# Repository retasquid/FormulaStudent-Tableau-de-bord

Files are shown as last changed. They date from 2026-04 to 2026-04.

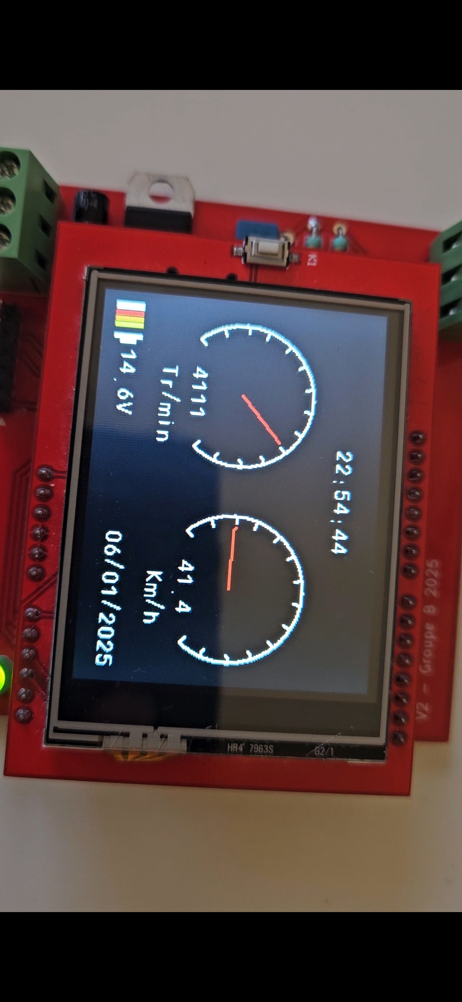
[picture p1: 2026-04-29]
photos/Page_ecran.jpg

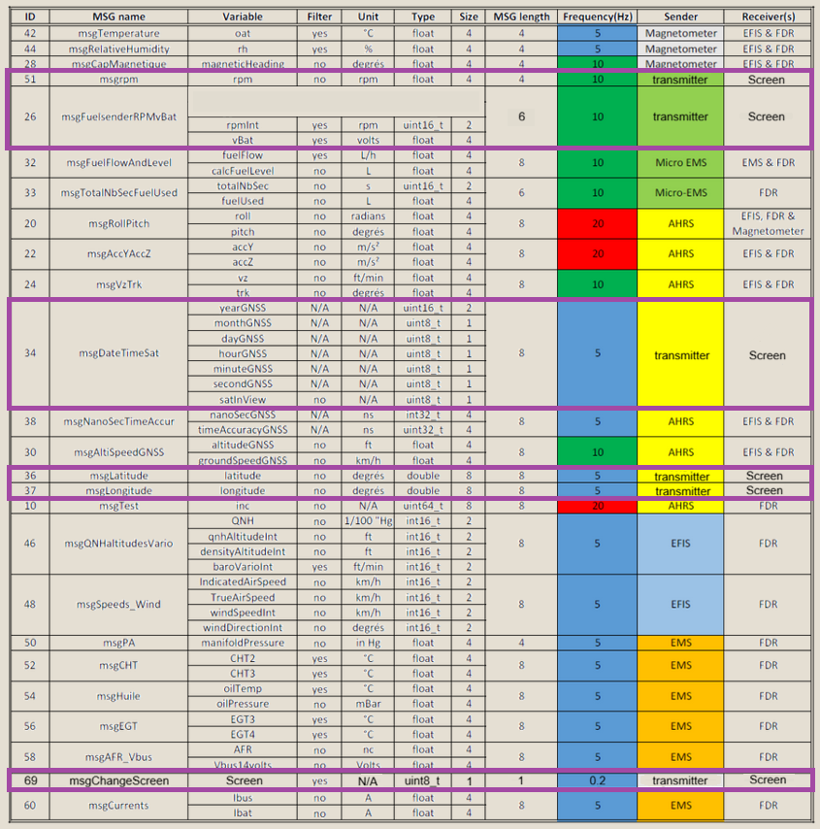
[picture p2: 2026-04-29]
photos/Correspondance_mesure_can_annote.PNG

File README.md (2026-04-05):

# 🏎️ PROJET FORMULA STUDENT - Système d'Affichage Temps Réel

Je suis fier de vous présenter notre travail réalisé dans le cadre du projet Formula Student à l'IUT Lyon 1 Villeurbanne Gratte-Ciel !

# 📍 Contexte :
Dans cette compétition automobile étudiante, plusieurs spécialités et groupes collaborent pour concevoir un véhicule de course. Matthia Pretotto et moi avons travaillé sur le système d'affichage des données du véhicule.

# ⚙️ Objectif du projet :
Développer un système capable d'acquérir, traiter et afficher en temps réel les données du tableau de bord via le bus CAN de la voiture de course.

# 📊 Fonctionnalités implémentées :
• Vitesse instantanée du véhicule
• Régime moteur (RPM)
• Heure actuelle
• Tension batterie
• Position GPS du véhicule

# 🛠️ Technologies employées :
Le projet se base sur un microcontrôleur 8 bits PIC18F27Q84 et un transceiver CAN pour interfacer le bus CAN. Le software a été réalisé en C depuis l'IDE MPLABX avec le plugin MCC pour simplifier la configuration des périphériques. Nous avons également conçu la carte électronique puis nous l'avons fait imprimer par un professionnel.

# 💡 Défis techniques relevés :
Les contraintes principales du projet étaient de réussir à rafraîchir rapidement l'écran malgré les limitations du microcontrôleur PIC et d'assurer une réception fiable des données provenant du bus CAN. Pour ce faire, nous avons développé des bibliothèques optimisées pour interagir efficacement avec le bus CAN et accélérer le calcul des jauges de l'écran, atteignant ainsi un taux de rafraîchissement d'environ 3Hz.

Merci à Mr. Ismael Bakiri et Mr. Anthony Chaussat pour leur encadrement et leur soutien tout au long de ce projet.

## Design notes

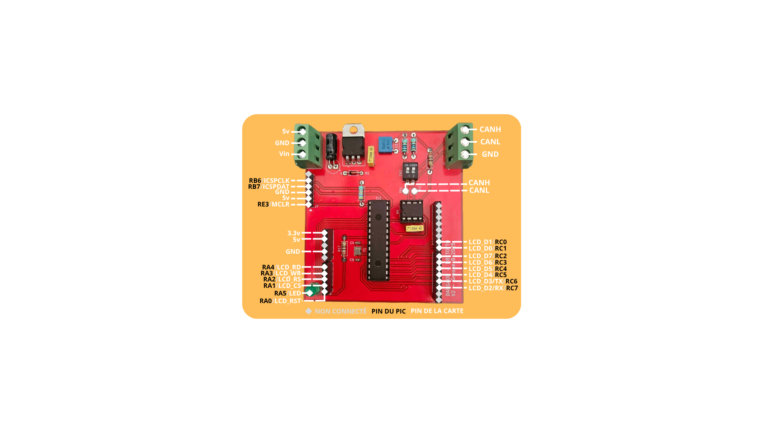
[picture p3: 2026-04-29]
photos/Carte_Formula_Student_Pinout.png

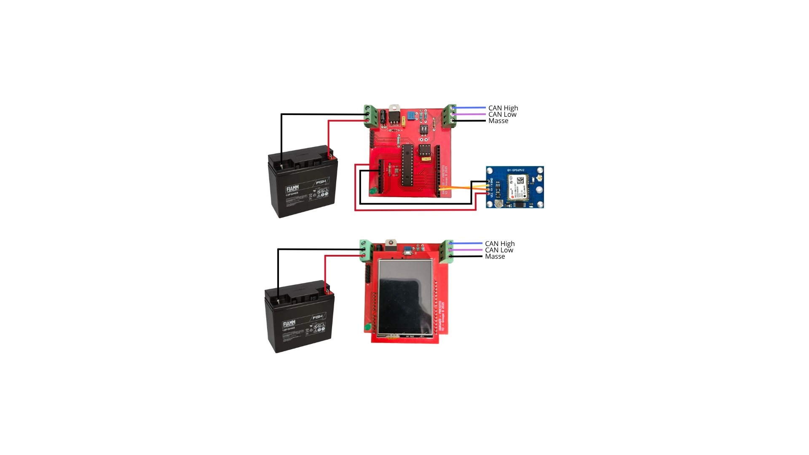
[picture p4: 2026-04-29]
photos/Cablage_cartes.png

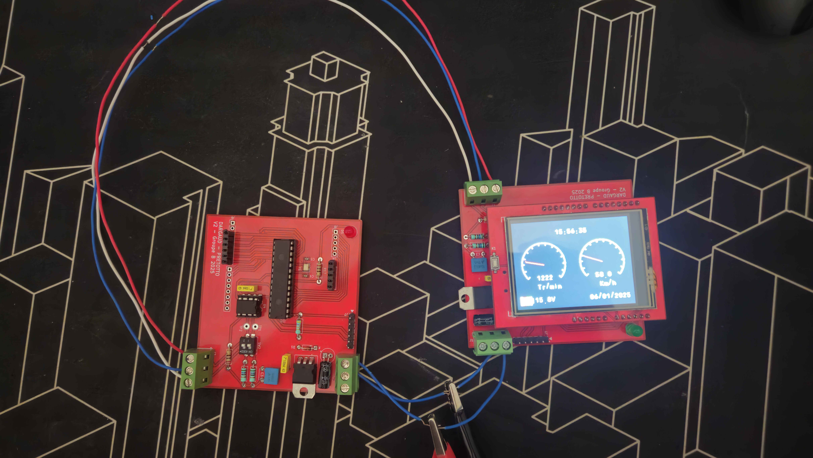
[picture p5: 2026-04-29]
photos/Cablage_reel_cartes.jpg

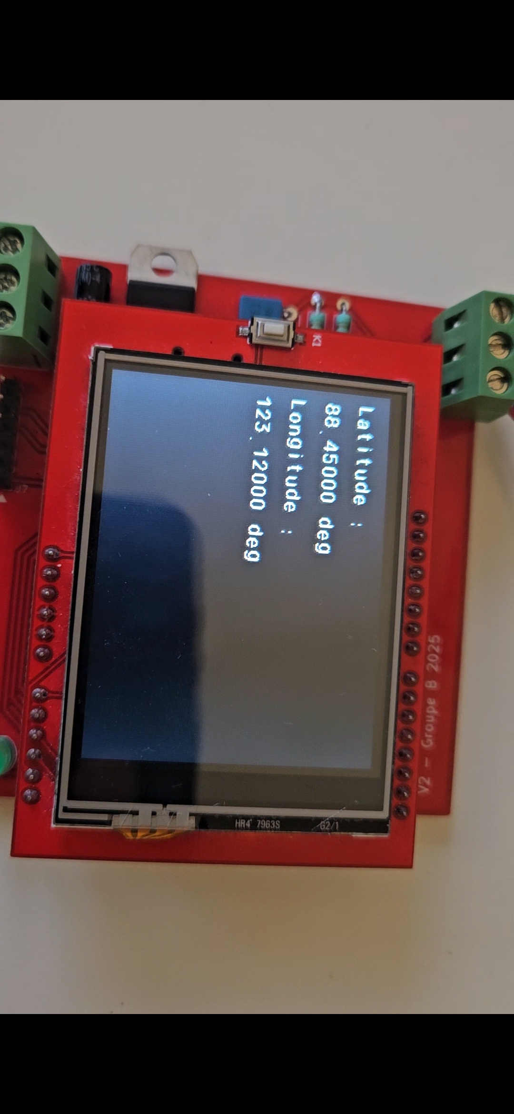
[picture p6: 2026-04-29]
photos/page_position.jpg

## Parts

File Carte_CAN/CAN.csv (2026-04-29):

Reference | Value | Footprint | Qty | Description
C1,C2 | 100 nF | IUT_CAO_empreintes:C_Disc_D4.7mm_W2.5mm_P5.00mm | 2 | Unpolarized capacitor
C3 | 10 nF | IUT_CAO_empreintes:C_Disc_D4.7mm_W2.5mm_P5.00mm | 1 | Unpolarized capacitor
C4,C5 | 20pF | Capacitor_SMD:C_0603_1608Metric | 2 | Unpolarized capacitor
C21 | 1uF | IUT_CAO_empreintes:CP_Radial_D6.3mm_P2.50mm | 1 | polarized capacitor
D1 | 1N4148 | Diode_THT:D_DO-35_SOD27_P7.62mm_Horizontal | 1 | 100V 0.15A standard switching diode, DO-35
D5 | LED | IUT_CAO_empreintes:LED_D5.0mm | 1
J1,J2 | Screw_Terminal_01x03 | G207_Laury_empreintes: Bornier_1x03_L15mm_W7.5mm_P5.00mm | 2 | Generic screw terminal, single row, 01x03
J3,J6 | Conn_01x08_Socket | Connector_PinHeader_2.54mm: PinHeader_1x08_P2.54mm_Vertical | 2 | Generic connector, single row, 01x08, script generated
J4,J8 | Conn_01x05_Socket | Connector_PinHeader_2.54mm: PinHeader_1x05_P2.54mm_Vertical | 2 | Generic connector, single row, 01x05, script generated
J7 | Conn_01x06_Pin | IUT_CAO_empreintes:PinHeader_1x06_P2.54mm_Vertical | 1
R14 | 47k | G207_Laury_empreintes: R_Axial_DIN0207_L6.3mm_D2.5mm_P10.16mm_Horizontal | 1
R17 | 270 | G207_Laury_empreintes: R_Axial_DIN0207_L6.3mm_D2.5mm_P10.16mm_Horizontal | 1
R18,R19 | 60 | G207_Laury_empreintes: R_Axial_DIN0207_L6.3mm_D2.5mm_P10.16mm_Horizontal | 2
R20 | 300 | G207_Laury_empreintes: R_Axial_DIN0207_L6.3mm_D2.5mm_P10.16mm_Horizontal | 1
SW2 | SW_DIP_x02 | IUT_CAO_empreintes: SW_DIP_SPSTx02_Slide_7.5x7.01mm_W7.62mm_P2.54mm_LowProfile | 1 | 2x DIP Switch, Single Pole Single Throw (SPST) switch, small symbol
TP1,TP2 | TestPoint | IUT_CAO_empreintes: TestPoint_Loop_D2.50mm_Drill1.0mm | 2 | test point
U1 | PIC18F27Q84 | PIC18F27Q84-E_SP:DIP787W45P254L3556H508Q28 | 1
U4 | MCP2561-E-P | Package_DIP:DIP-8_W7.62mm_LongPads | 1 | High-Speed CAN Transceiver, 1Mbps, 5V supply, -40C to +125C, DIP-8
U8 | L7805 | L7805CV:TO255P1040X460X1968-3 | 1 | Positive 1.5A 35V Linear Regulator, Fixed Output 5V, TO-220/TO-263/TO-252
Y1 | Crystal_GND23 | Crystal:Crystal_SMD_3225-4Pin_3.2x2.5mm | 1 | Four pin crystal, GND on pins 2 and 3
Screen | 2.4” TFT LCD | 4DLCD-24320240-IPS Arduino Shield Compatible | 1 | 2.4” TFT LCD Arduino Shield Compatible
GPS | Ublox NEO-6M | Connector_PinHeader_2.54mm: PinHeader_1x04_P2.54mm_Vertical | 1 | Ublox NEO-6M based GPS board

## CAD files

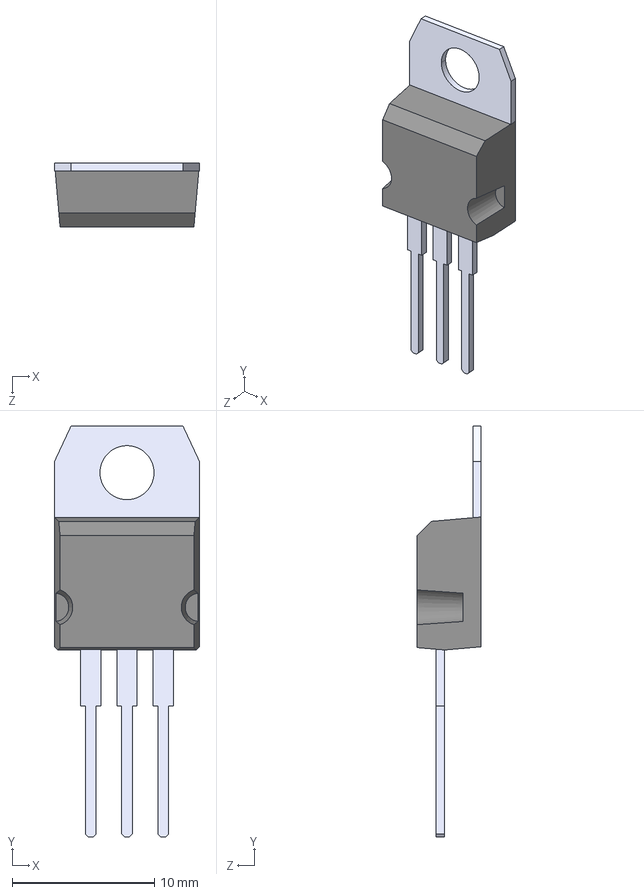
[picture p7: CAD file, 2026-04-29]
Carte_CAN/L7805CV/L7805CV.step
10.2 x 28.9 x 4.50 mm

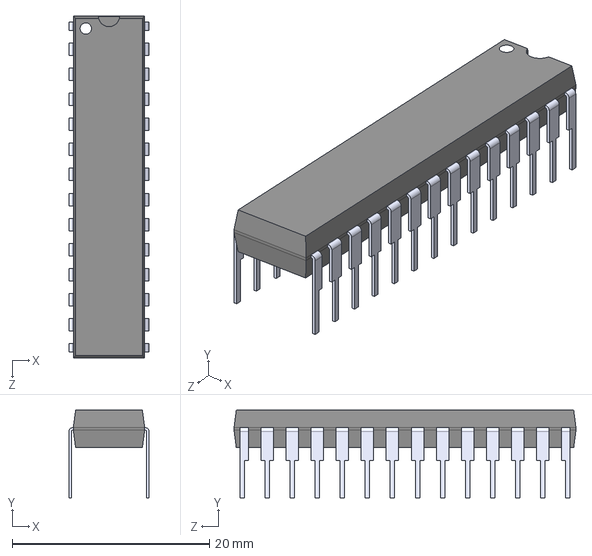
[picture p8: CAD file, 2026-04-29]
Carte_CAN/PIC18F27Q84-E_SP/PIC18F27Q84-E_SP.step
8.13 x 8.89 x 34.7 mm

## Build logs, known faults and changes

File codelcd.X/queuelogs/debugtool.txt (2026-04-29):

389 1761028267058 GEN4_TO_CONTROLLER_LOG:GEN4_PROGRAM_INT_LOG_PIC18F27Q84 Pre:endOfOperations
389 1761028267058 GEN4_TO_CONTROLLER_LOG:GEN4_PROGRAM_INT_LOG_PIC18F27Q84 Payload
389 1761028267058 GEN4_TO_CONTROLLER_LOG:GEN4_PROGRAM_INT_LOG_PIC18F27Q84 null
389 1761028267058 GEN4_TO_CONTROLLER_LOG:GEN4_PROGRAM_INT_LOG_PIC18F27Q84 Payload End
389 1761028267058 XXXX 1761028267058, Thread 389: XXXX 1761028267058, Entering Thread 389: Commands::runScriptBasic, script name = ExitTMOD, timeOut = -1 ms  
389 1761028267058 XXXX 1761028267058, Thread 389: com.Send returned false 
389 1761028267058 XXXX 1761028267058, Thread 389: transfer: exception after writeHeaderAndGetResult null 
389 1761028267058 XXXX 1761028267058, Thread 389: XXXX 1761028267058, Entering Thread 389: ToolCommUsb::recoverFromProtocolError, type = NO_SCRIPT  
389 1761028267058 XXXX 1761028267058, Thread 389: Send Abort Script Engine Command 
389 1761028267058 XXXX 1761028267058, Thread 389: XXXX 1761028267058, Entering Thread 389: ToolCommUsb::killScriptEngine  
389 1761028267059 XXXX 1761028267059, Thread 389: com.Send returned false 
389 1761028267059 XXXX 1761028267059, Thread 389: Failed sending Abort Script Engine Command. Set nuclear option = true 
389 1761028267059 XXXX 1761028267059, Thread 389: About to nuke 
389 1761028267059 XXXX 1761028267059, Thread 389: XXXX 1761028267059, Entering Thread 389: ToolCommUsb::nuclearOption  
389 1761028267060 XXXX 1761028267060, Thread 389: com.Send returned false

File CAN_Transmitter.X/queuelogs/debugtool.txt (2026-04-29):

340 1774035285568 GEN4_CONNECT_DIAGNOSTICS:MPLABCommTool is NOT null
340 1774035285568 GEN4_CONNECT_DIAGNOSTICS:AttachedToolPID = 9018, AttachedToolVID = 4d8
340 1774035285568 GEN4_CONNECT_DIAGNOSTICS:transport type = USB
340 1774035285568 GEN4_CONNECT_DIAGNOSTICS:AttachedToolPID = 9018, AttachedToolVID = 4d8
340 1774035286806 com.microchip.mplab.mdbcore.RealICETool.RIDbgToolCom
340 1774035286806 GEN4_CONNECT_DIAGNOSTICS:Before MPLABCommTool.Connect()
340 1774035286807 GEN4_CONNECT_DIAGNOSTICS:After MPLABCommTool.Connect()
340 1774035286807 GEN4_CONNECT_DIAGNOSTICS:MPLABCommTool.Connect() returned MPLABCOMM_NO_ERROR
340 1774035286807 GEN4_CONNECT_DIAGNOSTICS:Attaching to MPLABCommTool plugnplay
340 1774035286825 GEN4_CONNECT_DIAGNOSTICS:Adding new plug and play observer com.microchip.mplab.mdbcore.RI4Tool.RI4ToolBase$RI4PlugNPlayObserver@11f38d99
340 1774035286825 GEN4_CONNECT_DIAGNOSTICS:Begin PlugNPlayObservers list dump:
340 1774035286825 GEN4_CONNECT_DIAGNOSTICS:com.microchip.mplab.mdbcore.RI4Tool.RI4ToolBase$RI4PlugNPlayObserver@11f38d99
340 1774035286825 GEN4_CONNECT_DIAGNOSTICS:End PlugNPlayObservers list dump:
340 1774035286850 GEN4_CONNECT_DIAGNOSTICS:Registering for alternate PNP notifications. CommPnPCriteria.cPIDList = [9019, 901c, 2180], CommPnPCriteria.cSerialNumber = bur205171127
148 1774035287709 GEN4_CONNECT_DIAGNOSTICS:Calling Update on plug and play observer com.microchip.mplab.mdbcore.RI4Tool.RI4ToolBase$RI4PlugNPlayObserver@11f38d99
148 1774035287709 GEN4_CONNECT_DIAGNOSTICS:Entering plug and play Update(). Attached PID = 9018
148 1774035288523 com.microchip.mplab.mdbcore.RealICETool.RIDbgToolCom.HWToolConnected
148 1774035288523 GEN4_CONNECT_DIAGNOSTICS:Before MPLABCommTool.Connect()
148 1774035288523 GEN4_CONNECT_DIAGNOSTICS:After MPLABCommTool.Connect()
148 1774035288523 GEN4_CONNECT_DIAGNOSTICS:MPLABCommTool.Connect() returned MPLABCOMM_NO_ERROR
148 1774035288523 GEN4_CONNECT_DIAGNOSTICS:Before detaching from MPLABCommTool plugnplay
148 1774035288524 GEN4_CONNECT_DIAGNOSTICS:Attaching to MPLABCommTool plugnplay
148 1774035288524 GEN4_CONNECT_DIAGNOSTICS:Calling Update on plug and play observer com.microchip.mplab.mdbcore.RI4Tool.RI4ToolBase$RI4PlugNPlayObserver@11f38d99
148 1774035288524 GEN4_CONNECT_DIAGNOSTICS:Entering plug and play Update(). Attached PID = 9018
148 1774035292241 GEN4_CONNECT_DIAGNOSTICS:Calling Update on plug and play observer com.microchip.mplab.mdbcore.RI4Tool.RI4ToolBase$RI4PlugNPlayObserver@11f38d99
148 1774035292241 GEN4_CONNECT_DIAGNOSTICS:Entering plug and play Update(). Attached PID = 9018
148 1774035293047 com.microchip.mplab.mdbcore.RealICETool.RIDbgToolCom.HWToolConnected
148 1774035293047 GEN4_CONNECT_DIAGNOSTICS:Before MPLABCommTool.Connect()
148 1774035293047 GEN4_CONNECT_DIAGNOSTICS:After MPLABCommTool.Connect()
148 1774035293047 GEN4_CONNECT_DIAGNOSTICS:MPLABCommTool.Connect() returned MPLABCOMM_NO_ERROR
148 1774035293047 GEN4_CONNECT_DIAGNOSTICS:Before detaching from MPLABCommTool plugnplay
148 1774035293047 GEN4_CONNECT_DIAGNOSTICS:Attaching to MPLABCommTool plugnplay
148 1774035293047 GEN4_CONNECT_DIAGNOSTICS:Calling Update on plug and play observer com.microchip.mplab.mdbcore.RI4Tool.RI4ToolBase$RI4PlugNPlayObserver@11f38d99
148 1774035293047 GEN4_CONNECT_DIAGNOSTICS:Entering plug and play Update(). Attached PID = 9018

340 1774035297469 GEN4_TO_CONTROLLER_LOG:GEN4_INIT_INT_LOG_PIC18F27Q84 Pre:init
340 1774035297469 GEN4_TO_CONTROLLER_LOG:GEN4_INIT_INT_LOG_PIC18F27Q84 Payload
340 1774035297469 GEN4_TO_CONTROLLER_LOG:GEN4_INIT_INT_LOG_PIC18F27Q84 DeviceInfo: Values:
340 1774035297470 GEN4_TO_CONTROLLER_LOG:GEN4_INIT_INT_LOG_PIC18F27Q84 DeviceInfo: pcAddress = 000004f9, Vpp = 9,00, useRowEraseIfVoltageIsLow = true, voltageBelowWhichUseRowErase = 2,10, deviceName = PIC18F27Q84, programmerType = PIC18ENH_V2
340 1774035297470 GEN4_TO_CONTROLLER_LOG:GEN4_INIT_INT_LOG_PIC18F27Q84 DeviceInfo: MemInfo values:
340 1774035297470 GEN4_TO_CONTROLLER_LOG:GEN4_INIT_INT_LOG_PIC18F27Q84 DeviceInfo: mask = ffff, exists = true, startAddr = 00000000, endAddr = 0001ffff, rowSize = 0080, rowEraseSize = 0080, addrInc = 0002, widthProgram = 0002
340 1774035297470 GEN4_TO_CONTROLLER_LOG:GEN4_INIT_INT_LOG_PIC18F27Q84 DeviceInfo: mask = 00ff, exists = true, startAddr = 00300000, endAddr = 00300023, rowSize = 0001, rowEraseSize = 0000, addrInc = 0001, widthProgram = 0001
340 1774035297470 GEN4_TO_CONTROLLER_LOG:GEN4_INIT_INT_LOG_PIC18F27Q84 DeviceInfo: mask = 0000, exists = false, startAddr = 00000000, endAddr = 00000000, rowSize = 0000, rowEraseSize = 0080, addrInc = 0000, widthProgram = 0000
340 1774035297470 GEN4_TO_CONTROLLER_LOG:GEN4_INIT_INT_LOG_PIC18F27Q84 DeviceInfo: mask = 00ff, exists = true, startAddr = 00380000, endAddr = 003803ff, rowSize = 0001, rowEraseSize = 0000, addrInc = 0001, widthProgram = 0001
340 1774035297470 GEN4_TO_CONTROLLER_LOG:GEN4_INIT_INT_LOG_PIC18F27Q84 DeviceInfo: mask = ffff, exists = true, startAddr = 00200000, endAddr = 0020003f, rowSize = 0001, rowEraseSize = 0000, addrInc = 0002, widthProgram = 0002
340 1774035297470 GEN4_TO_CONTROLLER_LOG:GEN4_INIT_INT_LOG_PIC18F27Q84 DeviceInfo: mask = ffff, exists = true, startAddr = 00200000, endAddr = 002403ff, rowSize = 0080, rowEraseSize = 0080, addrInc = 0002, widthProgram = 0002
340 1774035297470 GEN4_TO_CONTROLLER_LOG:GEN4_INIT_INT_LOG_PIC18F27Q84 DeviceInfo: mask = 0000, exists = false, startAddr = 00000000, endAddr = 00000000, rowSize = 0000, rowEraseSize = 0000, addrInc = 0001, widthProgram = 0001
340 1774035297470 GEN4_TO_CONTROLLER_LOG:GEN4_INIT_INT_LOG_PIC18F27Q84 DeviceInfo: mask = 0000, exists = false, startAddr = 00000000, endAddr = 00000000, rowSize = 0000, rowEraseSize = 0000, addrInc = 0000, widthProgram = 0000
340 1774035297470 GEN4_TO_CONTROLLER_LOG:GEN4_INIT_INT_LOG_PIC18F27Q84 DeviceInfo: mask = 0000, exists = false, startAddr = 00000000, endAddr = 00000000, rowSize = 0000, rowEraseSize = 0000, addrInc = 0000, widthProgram = 0000
340 1774035297470 GEN4_TO_CONTROLLER_LOG:GEN4_INIT_INT_LOG_PIC18F27Q84 DeviceInfo: mask = 0000, exists = false, startAddr = 00000000, endAddr = 00000000, rowSize = 0000, rowEraseSize = 0000, addrInc = 0000, widthProgram = 0000
340 1774035297470 GEN4_TO_CONTROLLER_LOG:GEN4_INIT_INT_LOG_PIC18F27Q84 DeviceInfo: mask = 0000, exists = false, startAddr = 00000000, endAddr = 00000000, rowSize = 0000, rowEraseSize = 0000, addrInc = 0001, widthProgram = 0001
340 1774035297470 GEN4_TO_CONTROLLER_LOG:GEN4_INIT_INT_LOG_PIC18F27Q84 DeviceInfo: mask = 0000, exists = false, startAddr = 00000000, endAddr = 00000000, rowSize = 0000, rowEraseSize = 0000, addrInc = 0001, widthProgram = 0001
340 1774035297470 GEN4_TO_CONTROLLER_LOG:GEN4_INIT_INT_LOG_PIC18F27Q84 DeviceInfo: mask = 0000, exists = false, startAddr = 00000000, endAddr = 00000000, rowSize = 0000, rowEraseSize = 0000, addrInc = 0000, widthProgram = 0000
340 1774035297470 GEN4_TO_CONTROLLER_LOG:GEN4_INIT_INT_LOG_PIC18F27Q84 DeviceInfo: mask = 0000, exists = false, startAddr = 00000000, endAddr = 00000000, rowSize = 0000, rowEraseSize = 0000, addrInc = 0000, widthProgram = 0000
340 1774035297470 GEN4_TO_CONTROLLER_LOG:GEN4_INIT_INT_LOG_PIC18F27Q84 DeviceInfo: mask = 0000, exists = false, startAddr = 00000000, endAddr = 00000000, rowSize = 0000, rowEraseSize = 0000, addrInc = 0000, widthProgram = 0000
340 1774035297470 GEN4_TO_CONTROLLER_LOG:GEN4_INIT_INT_LOG_PIC18F27Q84 DeviceInfo: mask = 0000, exists = false, startAddr = 00000000, endAddr = 00000000, rowSize = 0000, rowEraseSize = 0000, addrInc = 0000, widthProgram = 0000
340 1774035297470 GEN4_TO_CONTROLLER_LOG:GEN4_INIT_INT_LOG_PIC18F27Q84 DeviceInfo: mask = 7fffffff, exists = true, startAddr = 003ffffe, endAddr = 003fffff, rowSize = 0001, rowEraseSize = 0000, addrInc = 0001, widthProgram = 0001
340 1774035297470 GEN4_TO_CONTROLLER_LOG:GEN4_INIT_INT_LOG_PIC18F27Q84 DeviceInfo: mask = 0000, exists = false, startAddr = 00000000, endAddr = 00000000, rowSize = 0000, rowEraseSize = 0000, addrInc = 0000, widthProgram = 0000
340 1774035297470 GEN4_TO_CONTROLLER_LOG:GEN4_INIT_INT_LOG_PIC18F27Q84 DeviceInfo: mask = ffff, exists = true, startAddr = 003c0000, endAddr = 003c000f, rowSize = 0080, rowEraseSize = 0000, addrInc = 0002, widthProgram = 0002
340 1774035297470 GEN4_TO_CONTROLLER_LOG:GEN4_INIT_INT_LOG_PIC18F27Q84 DeviceInfo: mask = ffff, exists = true, startAddr = 002c0000, endAddr = 002c003f, rowSize = 0080, rowEraseSize = 0000, addrInc = 0002, widthProgram = 0002
340 1774035297470 GEN4_TO_CONTROLLER_LOG:GEN4_INIT_INT_LOG_PIC18F27Q84 DeviceInfo: mask = 0000, exists = false, startAddr = 00000000, endAddr = 00000000, rowSize = 0000, rowEraseSize = 0000, addrInc = 0000, widthProgram = 0000
340 1774035297470 GEN4_TO_CONTROLLER_LOG:GEN4_INIT_INT_LOG_PIC18F27Q84 DeviceInfo: mask = 0000, exists = false, startAddr = 00000000, endAddr = 00000000, rowSize = 0000, rowEraseSize = 0000, addrInc = 0000, widthProgram = 0000
340 1774035297470 GEN4_TO_CONTROLLER_LOG:GEN4_INIT_INT_LOG_PIC18F27Q84 DeviceInfo: mask = 0000, exists = false, startAddr = 00000000, endAddr = 00000000, rowSize = 0000, rowEraseSize = 0000, addrInc = 0000, widthProgram = 0000
340 1774035297470 GEN4_TO_CONTROLLER_LOG:GEN4_INIT_INT_LOG_PIC18F27Q84 CfgRequiredBitsMask Values:
340 1774035297470 GEN4_TO_CONTROLLER_LOG:GEN4_INIT_INT_LOG_PIC18F27Q84 Address = 00300000, Mask = 00000077
340 1774035297470 GEN4_TO_CONTROLLER_LOG:GEN4_INIT_INT_LOG_PIC18F27Q84 Address = 00300001, Mask = 0000002b
340 1774035297470 GEN4_TO_CONTROLLER_LOG:GEN4_INIT_INT_LOG_PIC18F27Q84 Address = 00300002, Mask = 000000ff
340 1774035297470 GEN4_TO_CONTROLLER_LOG:GEN4_INIT_INT_LOG_PIC18F27Q84 Address = 00300003, Mask = 000000bf
340 1774035297470 GEN4_TO_CONTROLLER_LOG:GEN4_INIT_INT_LOG_PIC18F27Q84 Address = 00300004, Mask = 0000007f
340 1774035297470 GEN4_TO_CONTROLLER_LOG:GEN4_INIT_INT_LOG_PIC18F27Q84 Address = 00300005, Mask = 0000003f
340 1774035297470 GEN4_TO_CONTROLLER_LOG:GEN4_INIT_INT_LOG_PIC18F27Q84 Address = 00300006, Mask = 0000001f
340 1774035297470 GEN4_TO_CONTROLLER_LOG:GEN4_INIT_INT_LOG_PIC18F27Q84 Address = 00300007, Mask = 0000008f
340 1774035297470 GEN4_TO_CONTROLLER_LOG:GEN4_INIT_INT_LOG_PIC18F27Q84 Address = 00300008, Mask = 00000033
340 1774035297470 GEN4_TO_CONTROLLER_LOG:GEN4_INIT_INT_LOG_PIC18F27Q84 Address = 00300009, Mask = 00000001
340 1774035297470 GEN4_TO_CONTROLLER_LOG:GEN4_INIT_INT_LOG_PIC18F27Q84 Address = 0030000a, Mask = 000000ff
340 1774035297470 GEN4_TO_CONTROLLER_LOG:GEN4_INIT_INT_LOG_PIC18F27Q84 Address = 0030000b, Mask = 000000ff
340 1774035297470 GEN4_TO_CONTROLLER_LOG:GEN4_INIT_INT_LOG_PIC18F27Q84 Address = 0030000c, Mask = 000000ff
340 1774035297470 GEN4_TO_CONTROLLER_LOG:GEN4_INIT_INT_LOG_PIC18F27Q84 Address = 0030000d, Mask = 000000ff
340 1774035297470 GEN4_TO_CONTROLLER_LOG:GEN4_INIT_INT_LOG_PIC18F27Q84 Address = 0030000e, Mask = 000000ff
340 1774035297470 GEN4_TO_CONTROLLER_LOG:GEN4_INIT_INT_LOG_PIC18F27Q84 Address = 0030000f, Mask = 000000ff
340 1774035297470 GEN4_TO_CONTROLLER_LOG:GEN4_INIT_INT_LOG_PIC18F27Q84 Address = 00300010, Mask = 000000ff
340 1774035297470 GEN4_TO_CONTROLLER_LOG:GEN4_INIT_INT_LOG_PIC18F27Q84 Address = 00300011, Mask = 000000ff
340 1774035297470 GEN4_TO_CONTROLLER_LOG:GEN4_INIT_INT_LOG_PIC18F27Q84 Address = 00300012, Mask = 000000ff
340 1774035297470 GEN4_TO_CONTROLLER_LOG:GEN4_INIT_INT_LOG_PIC18F27Q84 Address = 00300013, Mask = 000000ff
340 1774035297470 GEN4_TO_CONTROLLER_LOG:GEN4_INIT_INT_LOG_PIC18F27Q84 Address = 00300014, Mask = 000000ff
340 1774035297470 GEN4_TO_CONTROLLER_LOG:GEN4_INIT_INT_LOG_PIC18F27Q84 Address = 00300015, Mask = 000000ff
340 1774035297470 GEN4_TO_CONTROLLER_LOG:GEN4_INIT_INT_LOG_PIC18F27Q84 Address = 00300016, Mask = 000000ff
340 1774035297470 GEN4_TO_CONTROLLER_LOG:GEN4_INIT_INT_LOG_PIC18F27Q84 Address = 00300017, Mask = 000000ff
340 1774035297470 GEN4_TO_CONTROLLER_LOG:GEN4_INIT_INT_LOG_PIC18F27Q84 Address = 00300018, Mask = 000000ff
340 1774035297470 GEN4_TO_CONTROLLER_LOG:GEN4_INIT_INT_LOG_PIC18F27Q84 Address = 00300019, Mask = 000000ff
340 1774035297470 GEN4_TO_CONTROLLER_LOG:GEN4_INIT_INT_LOG_PIC18F27Q84 Address = 0030001a, Mask = 000000ff
340 1774035297470 GEN4_TO_CONTROLLER_LOG:GEN4_INIT_INT_LOG_PIC18F27Q84 Address = 0030001b, Mask = 000000ff
340 1774035297470 GEN4_TO_CONTROLLER_LOG:GEN4_INIT_INT_LOG_PIC18F27Q84 Address = 0030001c, Mask = 000000ff
340 1774035297470 GEN4_TO_CONTROLLER_LOG:GEN4_INIT_INT_LOG_PIC18F27Q84 Address = 0030001d, Mask = 000000ff
340 1774035297470 GEN4_TO_CONTROLLER_LOG:GEN4_INIT_INT_LOG_PIC18F27Q84 Address = 0030001e, Mask = 000000ff
340 1774035297470 GEN4_TO_CONTROLLER_LOG:GEN4_INIT_INT_LOG_PIC18F27Q84 Address = 0030001f, Mask = 000000ff
340 1774035297471 GEN4_TO_CONTROLLER_LOG:GEN4_INIT_INT_LOG_PIC18F27Q84 Address = 00300020, Mask = 000000ff
340 1774035297471 GEN4_TO_CONTROLLER_LOG:GEN4_INIT_INT_LOG_PIC18F27Q84 Address = 00300021, Mask = 000000ff
340 1774035297471 GEN4_TO_CONTROLLER_LOG:GEN4_INIT_INT_LOG_PIC18F27Q84 Address = 00300022, Mask = 000000ff
340 1774035297471 GEN4_TO_CONTROLLER_LOG:GEN4_INIT_INT_LOG_PIC18F27Q84 BasicInfo: Values:
340 1774035297471 GEN4_TO_CONTROLLER_LOG:GEN4_INIT_INT_LOG_PIC18F27Q84 Payload End
340 1774035302291 GEN4_TO_CONTROLLER_LOG:GEN4_INIT_INT_LOG_PIC18F27Q84 Post:init
340 1774035302291 GEN4_TO_CONTROLLER_LOG:GEN4_INIT_INT_LOG_PIC18F27Q84 Return Value
340 1774035302291 GEN4_TO_CONTROLLER_LOG:GEN4_INIT_INT_LOG_PIC18F27Q84 none
340 1774035302291 GEN4_TO_CONTROLLER_LOG:GEN4_INIT_INT_LOG_PIC18F27Q84 Return End

340 1774035302291 GEN4_TO_CONTROLLER_LOG:GEN4_INIT_INT_LOG_PIC18F27Q84 Pre:GetInterfaceProvider
340 1774035302291 GEN4_TO_CONTROLLER_LOG:GEN4_INIT_INT_LOG_PIC18F27Q84 Payload
340 1774035302291 GEN4_TO_CONTROLLER_LOG:GEN4_INIT_INT_LOG_PIC18F27Q84 RI4DebugInterface
340 1774035302291 GEN4_TO_CONTROLLER_LOG:GEN4_INIT_INT_LOG_PIC18F27Q84 Payload End
340 1774035302291 GEN4_TO_CONTROLLER_LOG:GEN4_INIT_INT_LOG_PIC18F27Q84 Post:GetInterfaceProvider
340 1774035302291 GEN4_TO_CONTROLLER_LOG:GEN4_INIT_INT_LOG_PIC18F27Q84 Return Value
340 1774035302291 GEN4_TO_CONTROLLER_LOG:GEN4_INIT_INT_LOG_PIC18F27Q84 com.microchip.mplab.libs.RI4ToolsController.implementations.RI4DebugInterfaceImpl@63104aa2
340 1774035302291 GEN4_TO_CONTROLLER_LOG:GEN4_INIT_INT_LOG_PIC18F27Q84 Return End

340 1774035302443 GEN4_TO_CONTROLLER_LOG:GEN4_INIT_INT_LOG_PIC18F27Q84 Pre:GetInterfaceProvider
340 1774035302443 GEN4_TO_CONTROLLER_LOG:GEN4_INIT_INT_LOG_PIC18F27Q84 Payload
340 1774035302443 GEN4_TO_CONTROLLER_LOG:GEN4_INIT_INT_LOG_PIC18F27Q84 RI4ProgramInterface
340 1774035302443 GEN4_TO_CONTROLLER_LOG:GEN4_INIT_INT_LOG_PIC18F27Q84 Payload End
340 1774035302443 GEN4_TO_CONTROLLER_LOG:GEN4_INIT_INT_LOG_PIC18F27Q84 Post:GetInterfaceProvider
340 1774035302443 GEN4_TO_CONTROLLER_LOG:GEN4_INIT_INT_LOG_PIC18F27Q84 Return Value
340 1774035302443 GEN4_TO_CONTROLLER_LOG:GEN4_INIT_INT_LOG_PIC18F27Q84 com.microchip.mplab.libs.RI4ToolsController.implementations.RI4ProgramInterfaceImpl@e36b2b8
340 1774035302443 GEN4_TO_CONTROLLER_LOG:GEN4_INIT_INT_LOG_PIC18F27Q84 Return End

340 1774035302547 GEN4_TO_CONTROLLER_LOG:GEN4_INIT_INT_LOG_PIC18F27Q84 Pre:GetInterfaceProvider
340 1774035302547 GEN4_TO_CONTROLLER_LOG:GEN4_INIT_INT_LOG_PIC18F27Q84 Payload
340 1774035302547 GEN4_TO_CONTROLLER_LOG:GEN4_INIT_INT_LOG_PIC18F27Q84 RI4ConnectInterface
340 1774035302547 GEN4_TO_CONTROLLER_LOG:GEN4_INIT_INT_LOG_PIC18F27Q84 Payload End
340 1774035302549 GEN4_TO_CONTROLLER_LOG:GEN4_INIT_INT_LOG_PIC18F27Q84 Post:GetInterfaceProvider
340 1774035302549 GEN4_TO_CONTROLLER_LOG:GEN4_INIT_INT_LOG_PIC18F27Q84 Return Value
340 1774035302549 GEN4_TO_CONTROLLER_LOG:GEN4_INIT_INT_LOG_PIC18F27Q84 com.microchip.mplab.libs.PK4ToolsController.PK4ConnectInterfaceImpl@56d40347
340 1774035302549 GEN4_TO_CONTROLLER_LOG:GEN4_INIT_INT_LOG_PIC18F27Q84 Return End
340 1774035302610 GEN4_CONNECT_DIAGNOSTICS:acceptablePIDs = [9018, 9019, 901c]
340 1774035302610 GEN4_CONNECT_DIAGNOSTICS:otherPIDs = [2180]
340 1774035302610 GEN4_CONNECT_DIAGNOSTICS:Setting selected tool type to pk4
340 1774035302611 GEN4_CONNECT_DIAGNOSTICS:otherPIDs = [2180]
340 1774035302611 GEN4_CONNECT_DIAGNOSTICS:acceptablePIDs = [9018, 9019, 901c]

340 1774035302614 GEN4_TO_CONTROLLER_LOG:GEN4_CONNECT_INT_LOG_PIC18F27Q84 Pre:selectCore
340 1774035302614 GEN4_TO_CONTROLLER_LOG:GEN4_CONNECT_INT_LOG_PIC18F27Q84 Payload
340 1774035302614 GEN4_TO_CONTROLLER_LOG:GEN4_CONNECT_INT_LOG_PIC18F27Q84 PIC18F27Q84
340 1774035302614 GEN4_TO_CONTROLLER_LOG:GEN4_CONNECT_INT_LOG_PIC18F27Q84 Payload End
340 1774035302615 GEN4_TO_CONTROLLER_LOG:GEN4_CONNECT_INT_LOG_PIC18F27Q84 Post:selectCore
340 1774035302615 GEN4_TO_CONTROLLER_LOG:GEN4_CONNECT_INT_LOG_PIC18F27Q84 Return Value
340 1774035302615 GEN4_TO_CONTROLLER_LOG:GEN4_CONNECT_INT_LOG_PIC18F27Q84 none
340 1774035302615 GEN4_TO_CONTROLLER_LOG:GEN4_CONNECT_INT_LOG_PIC18F27Q84 Return End

340 1774035302615 GEN4_TO_CONTROLLER_LOG:GEN4_INIT_INT_LOG_PIC18F27Q84 Pre:GetInterfaceProvider
340 1774035302615 GEN4_TO_CONTROLLER_LOG:GEN4_INIT_INT_LOG_PIC18F27Q84 Payload
340 1774035302615 GEN4_TO_CONTROLLER_LOG:GEN4_INIT_INT_LOG_PIC18F27Q84 RI4ControllerDiagnosticsInterface
340 1774035302615 GEN4_TO_CONTROLLER_LOG:GEN4_INIT_INT_LOG_PIC18F27Q84 Payload End
340 1774035302615 GEN4_TO_CONTROLLER_LOG:GEN4_INIT_INT_LOG_PIC18F27Q84 Post:GetInterfaceProvider
340 1774035302615 GEN4_TO_CONTROLLER_LOG:GEN4_INIT_INT_LOG_PIC18F27Q84 Return Value
340 1774035302615 GEN4_TO_CONTROLLER_LOG:GEN4_INIT_INT_LOG_PIC18F27Q84 com.microchip.mplab.libs.RI4ToolsController.implementations.RI4ControllerDiagnosticsInterfaceImpl@79882382
340 1774035302615 GEN4_TO_CONTROLLER_LOG:GEN4_INIT_INT_LOG_PIC18F27Q84 Return End

340 1774035302615 GEN4_TO_CONTROLLER_LOG:GEN4_INIT_INT_LOG_PIC18F27Q84 Pre:GetInterfaceProvider
340 1774035302615 GEN4_TO_CONTROLLER_LOG:GEN4_INIT_INT_LOG_PIC18F27Q84 Payload
340 1774035302615 GEN4_TO_CONTROLLER_LOG:GEN4_INIT_INT_LOG_PIC18F27Q84 ProgrammerToGo
340 1774035302615 GEN4_TO_CONTROLLER_LOG:GEN4_INIT_INT_LOG_PIC18F27Q84 Payload End
340 1774035302615 GEN4_TO_CONTROLLER_LOG:GEN4_INIT_INT_LOG_PIC18F27Q84 Post:GetInterfaceProvider
340 1774035302615 GEN4_TO_CONTROLLER_LOG:GEN4_INIT_INT_LOG_PIC18F27Q84 Return Value
340 1774035302615 GEN4_TO_CONTROLLER_LOG:GEN4_INIT_INT_LOG_PIC18F27Q84 com.microchip.mplab.libs.RI4ToolsController.implementations.ProgrammerToGoImpl@438ba951
340 1774035302615 GEN4_TO_CONTROLLER_LOG:GEN4_INIT_INT_LOG_PIC18F27Q84 Return End

340 1774035302616 GEN4_TO_CONTROLLER_LOG:GEN4_INIT_INT_LOG_PIC18F27Q84 Pre:GetInterfaceProvider
340 1774035302616 GEN4_TO_CONTROLLER_LOG:GEN4_INIT_INT_LOG_PIC18F27Q84 Payload
340 1774035302616 GEN4_TO_CONTROLLER_LOG:GEN4_INIT_INT_LOG_PIC18F27Q84 Status
340 1774035302616 GEN4_TO_CONTROLLER_LOG:GEN4_INIT_INT_LOG_PIC18F27Q84 Payload End
340 1774035302616 GEN4_TO_CONTROLLER_LOG:GEN4_INIT_INT_LOG_PIC18F27Q84 Post:GetInterfaceProvider
340 1774035302616 GEN4_TO_CONTROLLER_LOG:GEN4_INIT_INT_LOG_PIC18F27Q84 Return Value
340 1774035302616 GEN4_TO_CONTROLLER_LOG:GEN4_INIT_INT_LOG_PIC18F27Q84 null
340 1774035302616 GEN4_TO_CONTROLLER_LOG:GEN4_INIT_INT_LOG_PIC18F27Q84 Return End
340 1774035302624 GEN4_CONNECT_DIAGNOSTICS:ENTERING: com.microchip.mplab.mdbcore.RI4Tool.ConnectionHandler.CheckForFWUpdates()
340 1774035302624 GEN4_CONNECT_DIAGNOSTICS:Created FirmwareUpdateHandler com.microchip.mplab.mdbcore.pk4hybrid.pk4hybridFirmwareUpdateHandler@592a2bb4
340 1774035302624 GEN4_CONNECT_DIAGNOSTICS:ENTERING: com.microchip.mplab.mdbcore.pk4hybrid.pk4hybridFirmwareUpdateHandler.UpdateFirmware(FirmwareInfo, UpdateMessage)
340 1774035302629 GEN4_CONNECT_DIAGNOSTICS:areWeInBoot returned false
340 1774035302629 GEN4_CONNECT_DIAGNOSTICS:inBoot = false
340 1774035302629 GEN4_CONNECT_DIAGNOSTICS:uMode = checkingVersions
340 1774035302629 GEN4_CONNECT_DIAGNOSTICS:selectedTool = pk4
340 1774035302629 GEN4_CONNECT_DIAGNOSTICS:current toolType = pk4
340 1774035302629 GEN4_CONNECT_DIAGNOSTICS:current tool mode = pk4
340 1774035302629 GEN4_CONNECT_DIAGNOSTICS:ENTERING: com.microchip.mplab.mdbcore.pk4hybrid.pk4hybridFirmwareUpdateHandler.GetUpdateInfo()
340 1774035302691 GEN4_CONNECT_DIAGNOSTICS:Parsing file  for firmware updates
340 1774035302691 GEN4_CONNECT_DIAGNOSTICS:ENTERING: com.microchip.mplab.mdbcore.pk4hybrid.pk4hybridFirmwareUpdateHandler.ParseSelectedVersionsFromJamFile()
340 1774035302692 GEN4_CONNECT_DIAGNOSTICS:Jame file line = snap_boot.hex,010155
340 1774035302692 GEN4_CONNECT_DIAGNOSTICS:Jame file line = scripts.xml,001008
340 1774035302692 GEN4_CONNECT_DIAGNOSTICS:Jame file line = snap_app1 020410, 0040C000
340 1774035302692 GEN4_CONNECT_DIAGNOSTICS:Jame file line = snap_app2 1.11.20, 00500000
340 1774035302692 GEN4_CONNECT_DIAGNOSTICS:Jame file line = snap_app3 000000, FFFFFFFF
340 1774035302692 GEN4_CONNECT_DIAGNOSTICS:Jame file line = snap_app4 000000, FFFFFFFF
340 1774035302692 GEN4_CONNECT_DIAGNOSTICS:Jame file line = snap_app5 000000, FFFFFFFF
340 1774035302692 GEN4_CONNECT_DIAGNOSTICS:Jame file line = snap_app6 000000, FFFFFFFF
340 1774035302692 GEN4_CONNECT_DIAGNOSTICS:Jame file line = snap_app7 000000, FFFFFFFF
340 1774035302692 GEN4_CONNECT_DIAGNOSTICS:Jame file line = snap_app8 000000, FFFFFFFF
340 1774035302692 GEN4_CONNECT_DIAGNOSTICS:EXITING: com.microchip.mplab.mdbcore.pk4hybrid.pk4hybridFirmwareUpdateHandler.ri4ParseSelectedVersionsFromJamFile()
340 1774035302692 GEN4_CONNECT_DIAGNOSTICS:EXITING: com.microchip.mplab.mdbcore.pk4hybrid.pk4hybridFirmwareUpdateHandler.GetUpdateInfo()
340 1774035302692 GEN4_CONNECT_DIAGNOSTICS:current toolType = pk4

340 1774035302692 GEN4_TO_CONTROLLER_LOG:GEN4_CONNECT_INT_LOG_PIC18F27Q84 Pre:EstablishCommunincations
340 1774035302692 GEN4_TO_CONTROLLER_LOG:GEN4_CONNECT_INT_LOG_PIC18F27Q84 Payload
340 1774035302692 GEN4_TO_CONTROLLER_LOG:GEN4_CONNECT_INT_LOG_PIC18F27Q84 com.microchip.mplab.mdbcore.PK4Tool.PK4Com@7adc343f
340 1774035302692 GEN4_TO_CONTROLLER_LOG:GEN4_CONNECT_INT_LOG_PIC18F27Q84 Payload End
340 1774035302700 GEN4_TO_CONTROLLER_LOG:GEN4_CONNECT_INT_LOG_PIC18F27Q84 Post:EstablishCommunincations
340 1774035302700 GEN4_TO_CONTROLLER_LOG:GEN4_CONNECT_INT_LOG_PIC18F27Q84 Return Value
340 1774035302701 GEN4_TO_CONTROLLER_LOG:GEN4_CONNECT_INT_LOG_PIC18F27Q84 true
340 1774035302701 GEN4_TO_CONTROLLER_LOG:GEN4_CONNECT_INT_LOG_PIC18F27Q84 Return End

340 1774035302701 GEN4_TO_CONTROLLER_LOG:GEN4_CONNECT_INT_LOG_PIC18F27Q84 Pre:GetFirmwareInfo
340 1774035302701 GEN4_TO_CONTROLLER_LOG:GEN4_CONNECT_INT_LOG_PIC18F27Q84 Payload
340 1774035302701 GEN4_TO_CONTROLLER_LOG:GEN4_CONNECT_INT_LOG_PIC18F27Q84 null
340 1774035302701 GEN4_TO_CONTROLLER_LOG:GEN4_CONNECT_INT_LOG_PIC18F27Q84 Payload End
340 1774035302705 XXXX 1774035302705, Thread 340: com.Send returned false 
340 1774035302706 XXXX 1774035302706, Thread 340: execCommand: exception after writeSideChanel null

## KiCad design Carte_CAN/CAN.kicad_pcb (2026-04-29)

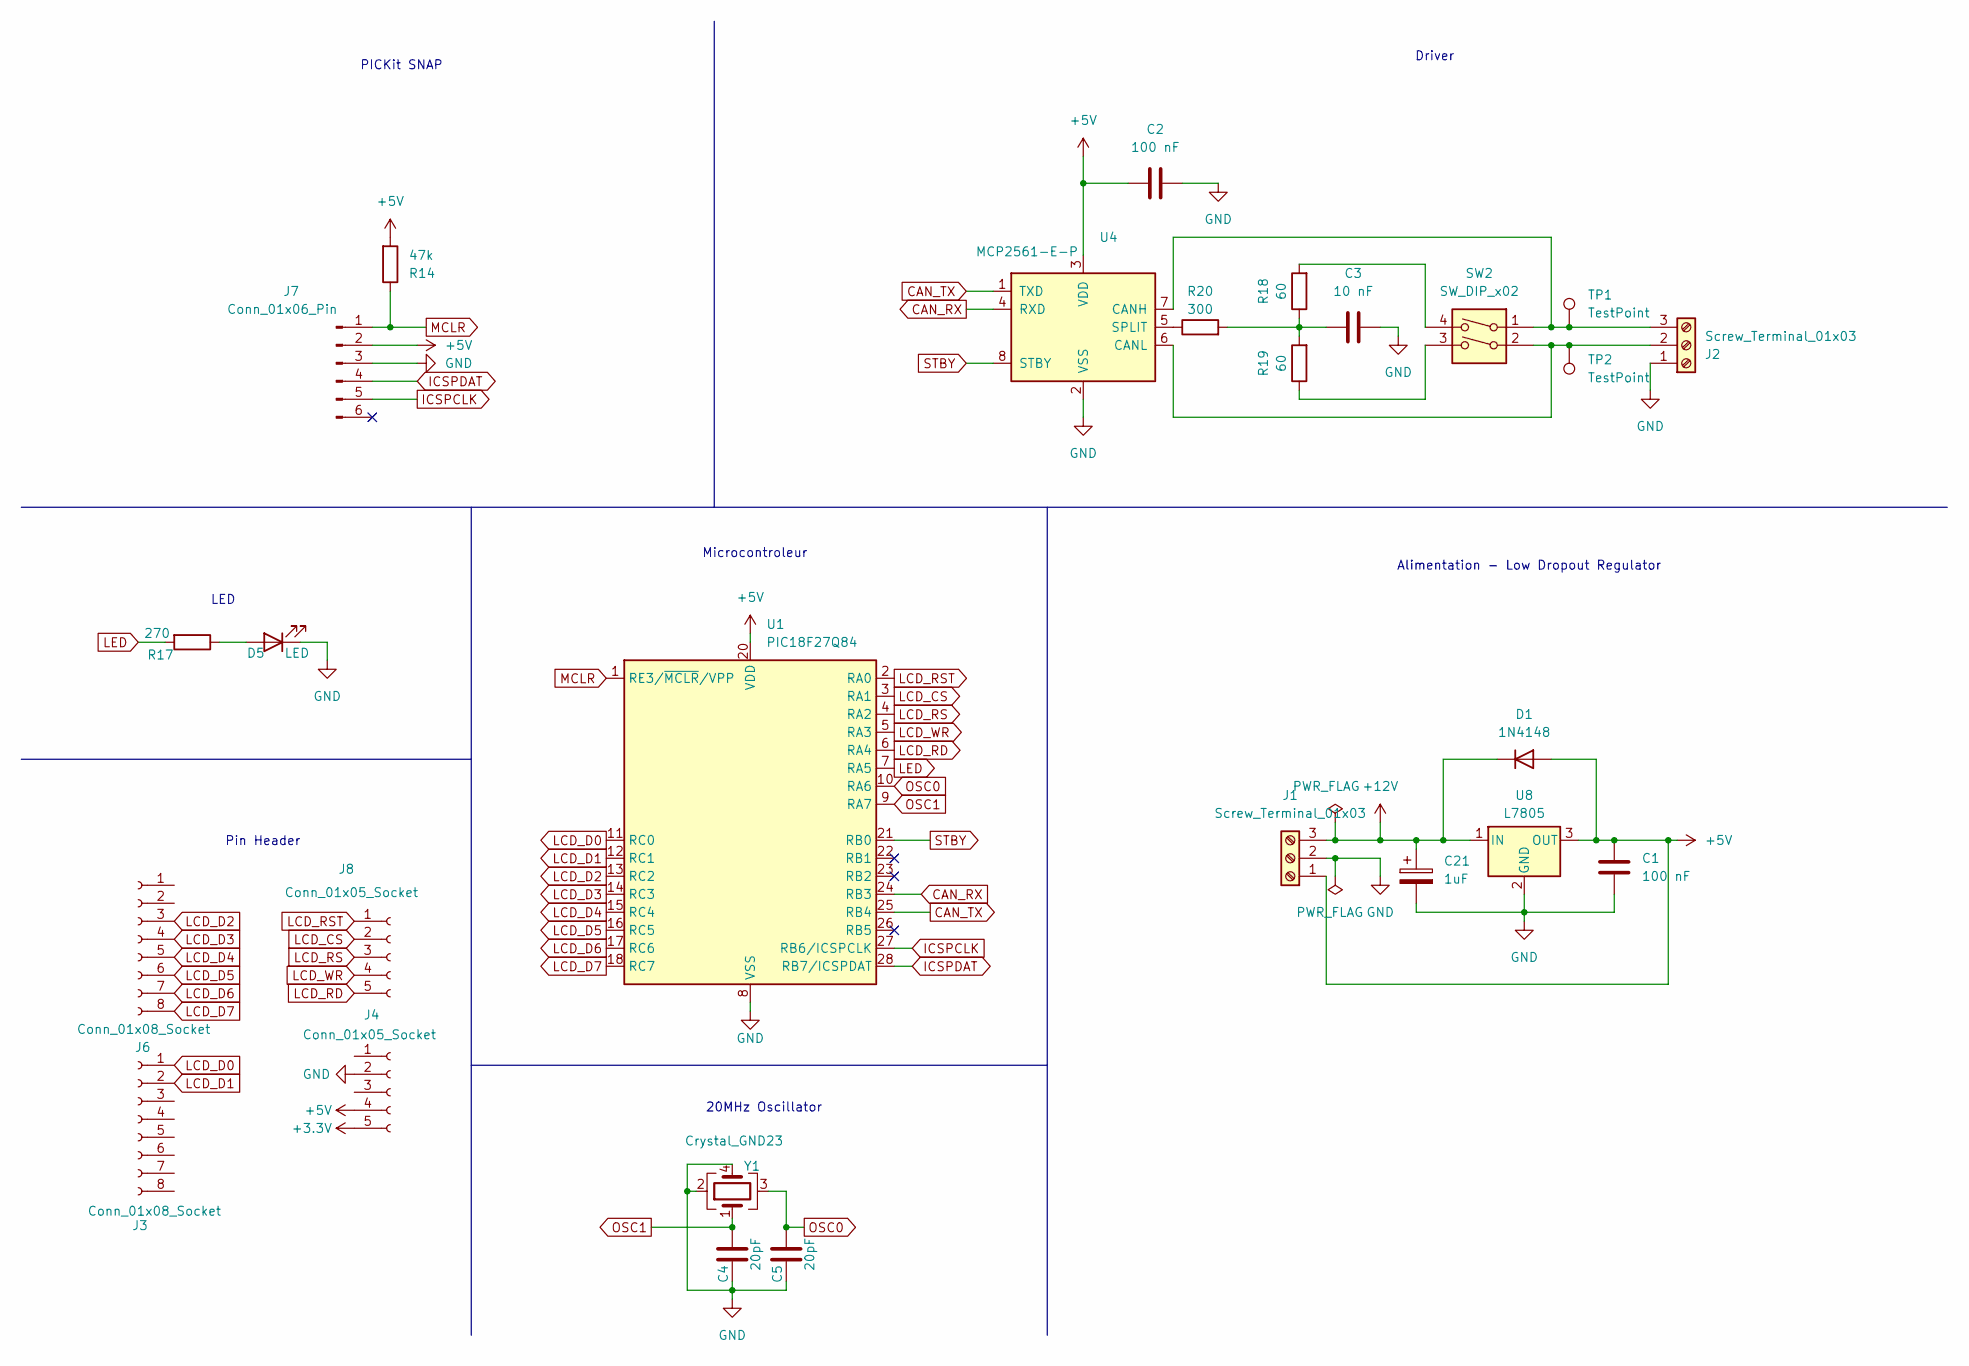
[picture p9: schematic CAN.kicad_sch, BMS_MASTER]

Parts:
C1, C2: 100 nF; C_Disc_D4.7mm_W2.5mm_P5.00mm
C3: 10 nF; C_Disc_D4.7mm_W2.5mm_P5.00mm
C4, C5: 20pF; C_0603_1608Metric
C21: 1uF; CP_Radial_D6.3mm_P2.50mm
D1: 1N4148; D_DO-35_SOD27_P7.62mm_Horizontal
D5: LED; LED_D5.0mm
J1, J2: Screw_Terminal_01x03; Bornier_1x03_L15mm_W7.5mm_P5.00mm
J3, J6: Conn_01x08_Socket; PinHeader_1x08_P2.54mm_Vertical
J4, J8: Conn_01x05_Socket; PinHeader_1x05_P2.54mm_Vertical
J7: Conn_01x06_Pin; PinHeader_1x06_P2.54mm_Vertical
R14: 47k; R_Axial_DIN0207_L6.3mm_D2.5mm_P10.16mm_Horizontal
R17: 270; R_Axial_DIN0207_L6.3mm_D2.5mm_P10.16mm_Horizontal
R18, R19: 60; R_Axial_DIN0207_L6.3mm_D2.5mm_P10.16mm_Horizontal
R20: 300; R_Axial_DIN0207_L6.3mm_D2.5mm_P10.16mm_Horizontal
SW2: SW_DIP_x02; SW_DIP_SPSTx02_Slide_7.5x7.01mm_W7.62mm_P2.54mm_LowProfile
TP1, TP2: TestPoint; TestPoint_Loop_D2.50mm_Drill1.0mm
U1: PIC18F27Q84; DIP787W45P254L3556H508Q28
U4: MCP2561-E-P; DIP-8_W7.62mm_LongPads
U8: L7805; TO255P1040X460X1968-3
Y1: Crystal_GND23; Crystal_SMD_3225-4Pin_3.2x2.5mm

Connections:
+3.3V: J4.5
+5V: C1.1, C2.1, D1.2 (A), J1.1, J4.4, J7.2, R14.2, U1.20 (VDD), U4.3 (VDD), U8.3 (OUT)
+12V: C21.1, D1.1 (K), J1.3, U8.1 (IN)
CAN_RX: U1.24 (RB3), U4.4 (RXD)
CAN_TX: U1.25 (RB4), U4.1 (TXD)
GND: C1.2, C2.2, C3.2, C4.2, C5.2, C21.2, D5.1 (K), J1.2, J2.1, J4.2, J7.3, U1.8 (VSS), U1.19 (VSS), U4.2 (VSS), U8.2 (GND), Y1.2, Y1.4
ICSPCLK: J7.5, U1.27 (RB6/ICSPCLK)
ICSPDAT: J7.4, U1.28 (RB7/ICSPDAT)
LCD_CS: J8.2, U1.3 (RA1)
LCD_D0: J3.1, U1.11 (RC0)
LCD_D1: J3.2, U1.12 (RC1)
LCD_D2: J6.3, U1.13 (RC2)
LCD_D3: J6.4, U1.14 (RC3)
LCD_D4: J6.5, U1.15 (RC4)
LCD_D5: J6.6, U1.16 (RC5)
LCD_D6: J6.7, U1.17 (RC6)
LCD_D7: J6.8, U1.18 (RC7)
LCD_RD: J8.5, U1.6 (RA4)
LCD_RS: J8.3, U1.4 (RA2)
LCD_RST: J8.1, U1.2 (RA0)
LCD_WR: J8.4, U1.5 (RA3)
LED: R17.2, U1.7 (RA5)
MCLR: J7.1, R14.1, U1.1 (RE3/~MCLR/VPP)
unnamed: C3.1, R18.1, R19.2, R20.2
unnamed: D5.2 (A), R17.1
unnamed: J2.2, SW2.2, TP2.1, U4.6 (CANL)
unnamed: J2.3, SW2.1, TP1.1, U4.7 (CANH)
unnamed: R18.2, SW2.4
unnamed: R19.1, SW2.3
unnamed: R20.1, U4.5 (SPLIT)
OSC0: C5.1, U1.10 (RA6), Y1.3
OSC1: C4.1, U1.9 (RA7), Y1.1
STBY: U1.21 (RB0), U4.8 (STBY)

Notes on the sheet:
Microcontroleur
LED
Alimentation - Low Dropout Regulator
Driver
PICKit SNAP
Pin Header
20MHz Oscillator

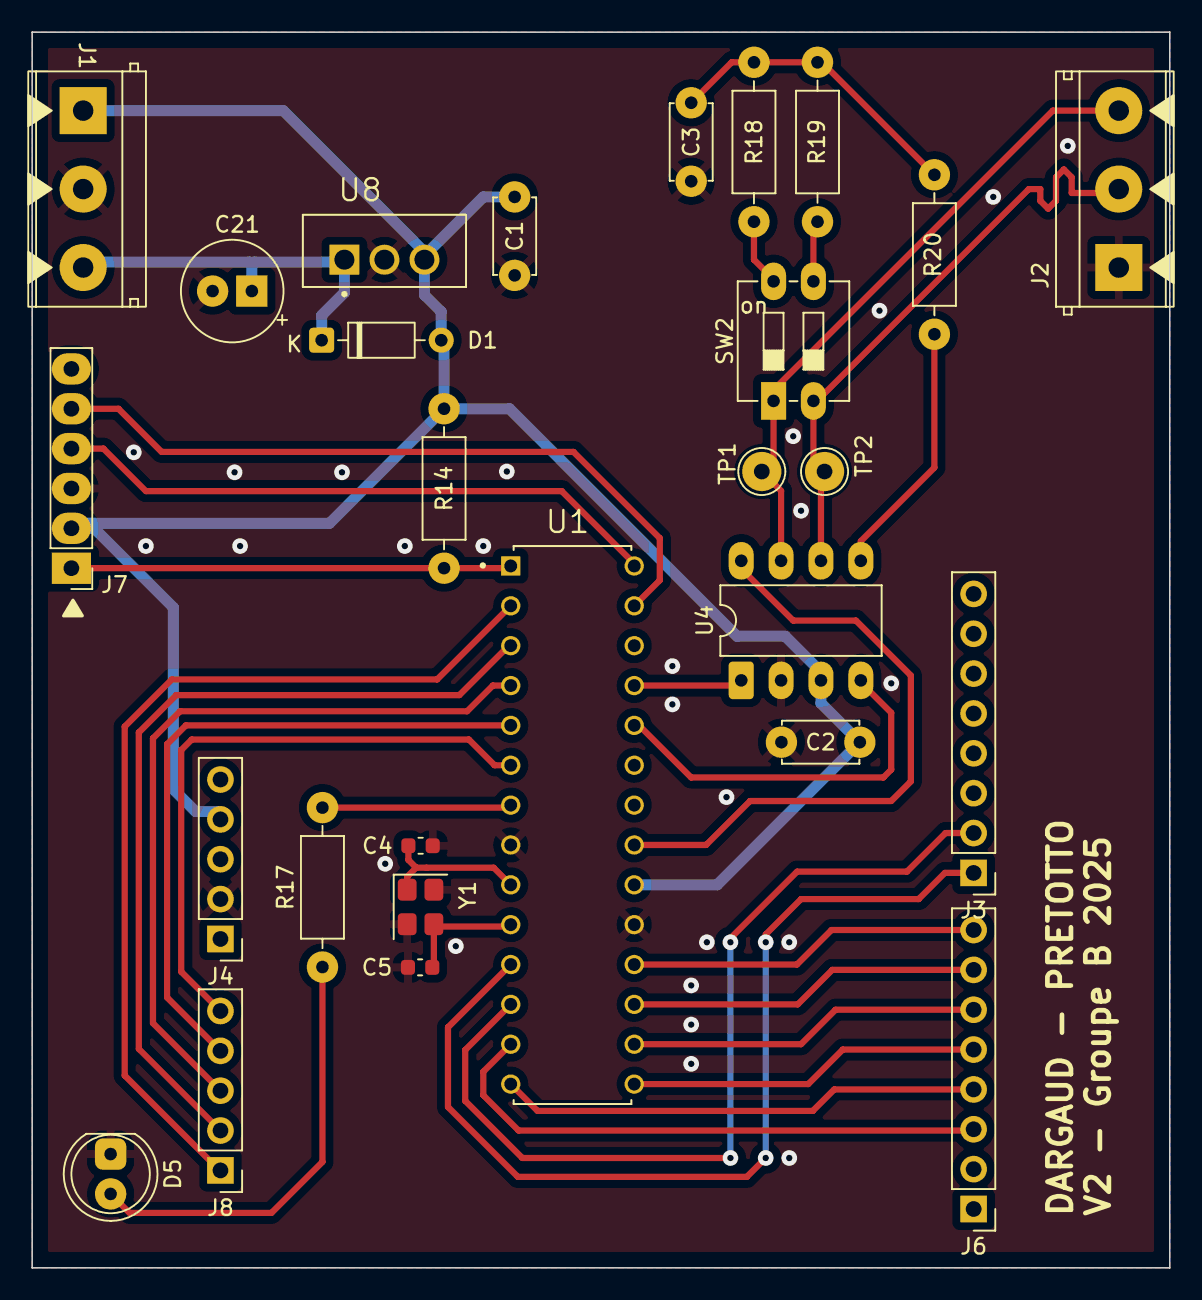
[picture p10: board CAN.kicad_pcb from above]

Board: 2 copper layers, 72.5 x 78.8 mm, 27 parts (0 on the bottom side), 32 nets.

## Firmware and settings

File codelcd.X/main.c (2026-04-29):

#include "mcc_generated_files/mcc.h"
#include <stdio.h>
#include <stdlib.h>
#include <string.h>
#include "compteur_vitesse.h"
#include <math.h>
#include "CAN_format.h"
#include "displayFunctions.h"

int main(void) {
    // Declaration d'une structure pour recevoir les messages CAN
    CAN_MSG_OBJ rxMessage;

    // Variable pour stocker la vitesse sous forme flottante
    FloatToBytes vitesse;
    vitesse.f32 = 0.0f;

    // Initialisation du systeme et des peripherals MCC
    SYSTEM_Initialize();

    // Initialisation de l'ecran
    ptrScreenInit();

    // Dessin des arcs de base pour le speedometre et le compte-tours
    ScreenDrawArc(120, 240, 60, -130, 130, 0xFFFF); // Speedometre
    ScreenDrawArc(120, 80, 60, -130, 130, 0xFFFF);  // Compte-tours

    // Initialisation des LED et STBY a l'etat bas
    LED_SetLow();
    STBY_SetLow();

    // Variable pour suivre l'ecran courant
    static uint8_t screen;

    // Boucle principale infinie
    while (1) {
        // Verification de la reception d'un message CAN
        if (CAN1_Receive(&rxMessage)) {

            // Traitement en fonction de l'ecran courant
            if (screen == 0) { // Ecran principal : vitesse, tr/min, date/heure
                switch (rxMessage.msgId) {
                    case 51: // Message de vitesse km/h
                        LED_SetHigh();          // Allumer LED indicatrice
                        GetMsgKmh(rxMessage.data);
                        LED_SetLow();           // Eteindre LED
                        break;

                    case 26: // Message de compte-tours et tension batterie
                        LED_SetHigh();
                        GetMsgTrminVbat(rxMessage.data);
                        LED_SetLow();
                        break;

                    case 34: // Message date et heure
                        LED_SetHigh();
                        GetMsgDateTime(rxMessage.data);
                        LED_SetLow();
                        break;

                    case 69: // Message de changement d'ecran
                        LED_SetHigh();
                        screen = GetScreenSwitch(rxMessage.data);
                        LED_SetLow();
                        break;

                    default: // Message inconnu : clignotement LED pour debug
                        LED_SetLow();
                        __delay_ms(1000);
                        LED_SetHigh();
                        __delay_ms(1000);
                }
            } 
            else if (screen == 1) { // Ecran secondaire : GPS (latitude / longitude)
                switch (rxMessage.msgId) {
                    case 36: // Message latitude
                        LED_SetHigh();
                        GetMsgLatitude(rxMessage.data);
                        LED_SetLow();
                        break;

                    case 37: // Message longitude
                        LED_SetHigh();
                        GetMsgLongitude(rxMessage.data);
                        LED_SetLow();
                        break;

                    case 69: // Message changement d'ecran
                        LED_SetHigh();
                        screen = GetScreenSwitch(rxMessage.data);
                        LED_SetLow();
                        break;

                    default: // Message inconnu : clignotement LED pour debug
                        LED_SetLow();
                        __delay_ms(1000);
                        LED_SetHigh();
                        __delay_ms(1000);
                }
            }
        }
    }

    return 0;
}

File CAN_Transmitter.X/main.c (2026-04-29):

/*
 * Auteur : Noe Dargaud
 * Date de modification : 21 mars 2026
 * Description : ce programme genere des donnees aleatoires
 * et recupere des donnees GPS afin de les transmettre sur le bus CAN
 */

#include "mcc_generated_files/mcc.h"
#include "CAN_format.h"
#include "rand.h"
#include "RTC.h"
#include "GPS.h"

GPS_Message_t GpsMsg;
DateHeure horodatage;

void main(void) {
    SYSTEM_Initialize();
    UART1_SetRxInterruptHandler(GPSRxISR);  // Initialisation de l'interruption GPS
    INTERRUPT_GlobalInterruptEnable();
    STBY_SetLow();                          // Activation du module CAN
    srand16(TMR2);                          // Initialisation de la seed RNG avec un timer
    initDateTime(&horodatage);
    LED_SetLow();
    GPS_init();
    __delay_ms(100);
    
    while (1) {
        LED_SetHigh();

        // Mise a jour de l'heure
        getTime(&horodatage, &GpsMsg);
        
        // Affichage des donnees sur l'ecran principal
        msgScreenSwitch(0);
        
        /* Envoi des informations aleatoires a la carte ecran */
        msgKmh((float)(rand16(0, 2500) / 10.0));
        
        msgTrminVbat(rand16(0, 6000), (float)(rand16(120, 160) / 10.0));
        
        msgDateTime(&horodatage);
        
        LED_SetLow();
        __delay_ms(5000);
        LED_SetHigh();
        
        // Affichage des donnees sur l'ecran secondaire
        msgScreenSwitch(1);
        
        /* Reception et copie securisee du message GPS */
        INTERRUPT_GlobalInterruptDisable();
        if(GPSRxReady){
            GPSRxReady = 0;
            strncpy(GPSMessage_safe, (const char*)GPSMessage, RX_BUFFER_SIZE);
        }
        INTERRUPT_GlobalInterruptEnable();

        // Parsing de la trame GPS
        GPGLL_Parser(GPSMessage_safe, &GpsMsg);

        /* Envoi des informations GPS a la carte ecran */
        msgLatitude(GpsMsg.latitude);
        msgLongitude(GpsMsg.longitude);
        
        __delay_ms(10);
        LED_SetLow();
        __delay_ms(5000);
    }
}
